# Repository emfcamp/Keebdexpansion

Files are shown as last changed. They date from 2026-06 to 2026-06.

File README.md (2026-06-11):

# KeebDeck Hexpansion

A keyboard hexpansion for the [Tildagon badge](https://tildagon.badge.emfcamp.org/) using the [solder.party KeebDeck Keyboard](https://www.solder.party/docs/keebdeck/keyboard/). Software for the hexpansion is [provided by @sodoku](https://github.com/sodoku/tildagon-keebdeck).

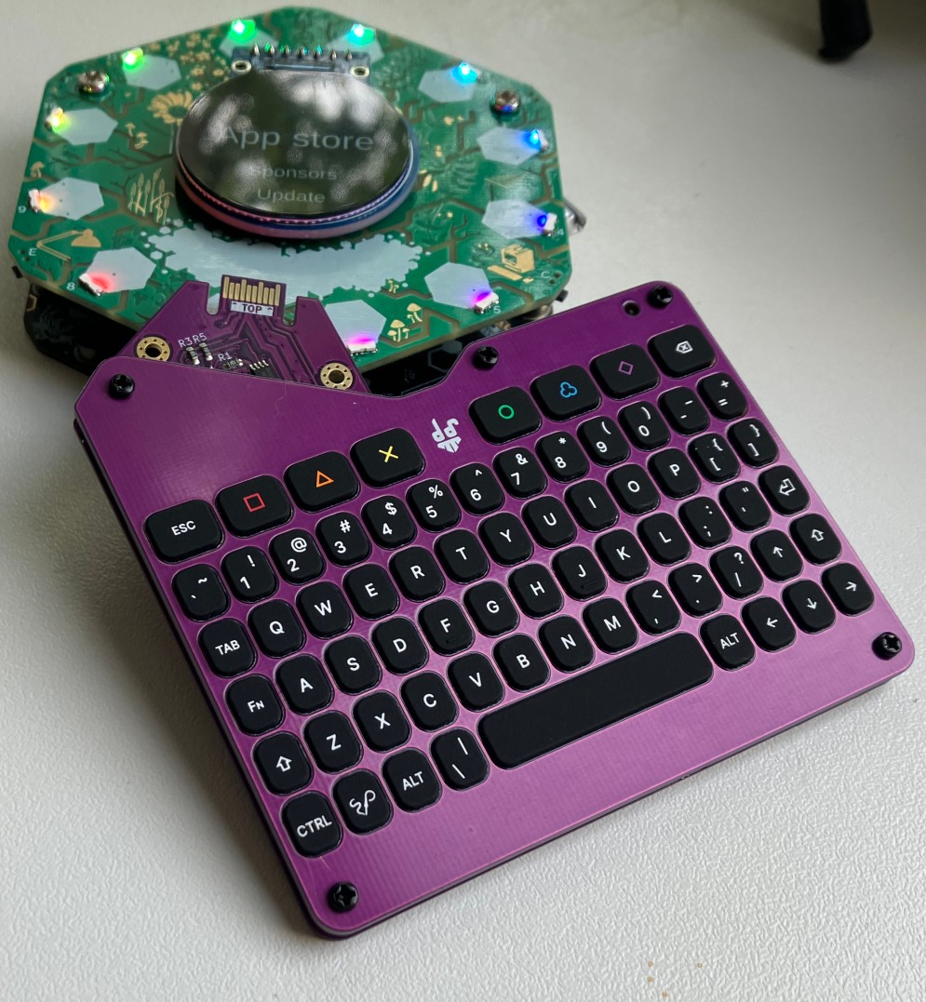
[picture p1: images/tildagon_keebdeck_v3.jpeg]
KeepDeck Hexpansion V3 next to the Tildagon


## Features

- Full layout keyboard
- RGB Backlit keys
- Type in text inputs
- Auto-installs driver when plugged in

Available for EMF 2026 camp ticket holders on the emfcamp website. See [here](https://blog.emfcamp.org/2026/05/28/tildagon-2026-spaceagon/) for more info

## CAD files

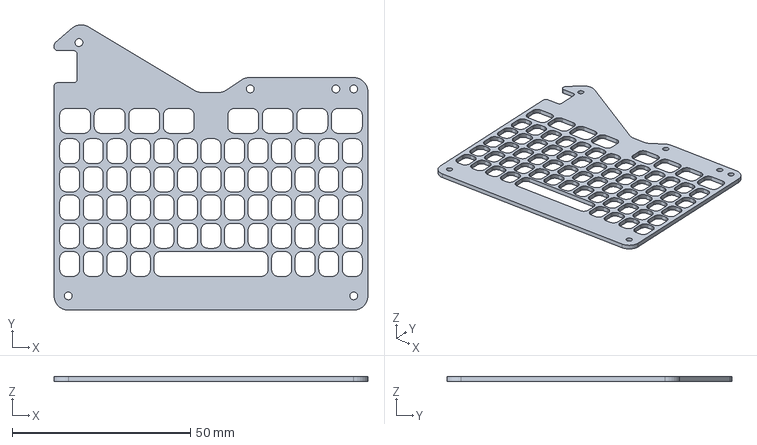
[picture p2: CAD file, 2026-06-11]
KiCad/frontplate/frontplate.step
88.0 x 80.0 x 1.51 mm

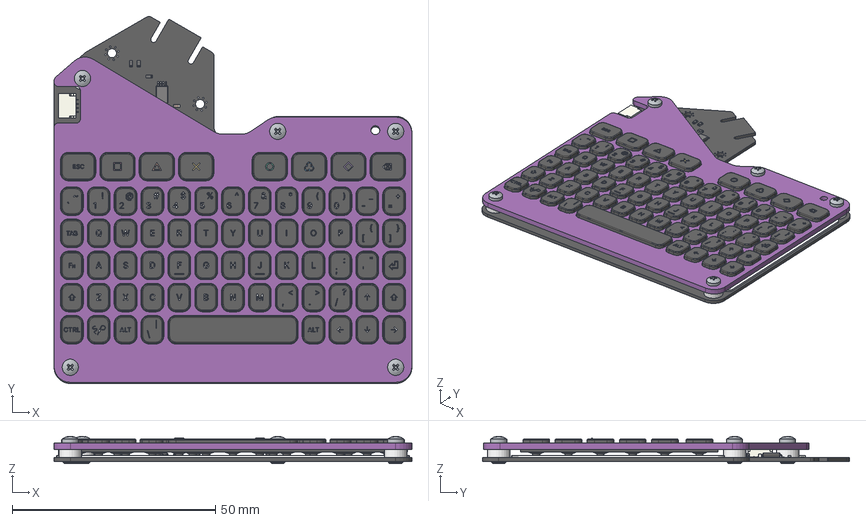
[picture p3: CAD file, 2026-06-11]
KiCad/keebdexpansion.step
88.0 x 90.3 x 6.70 mm
JST_SH_SM04B-SRSS-TB_1x04-1MP_P1.00mm_Horizontal
SMTSO2020CTJ x 5
M2x4 x 5
TSSOP-8_4.4x3mm_P0.65mm
C_0603_1608Metric x 2
C_0402_1005Metric
R_0603_1608Metric x 5
dome_sheet_6x13
keyboard_6x13
frontplate_PCB
TSOT-23-6
main_PCB

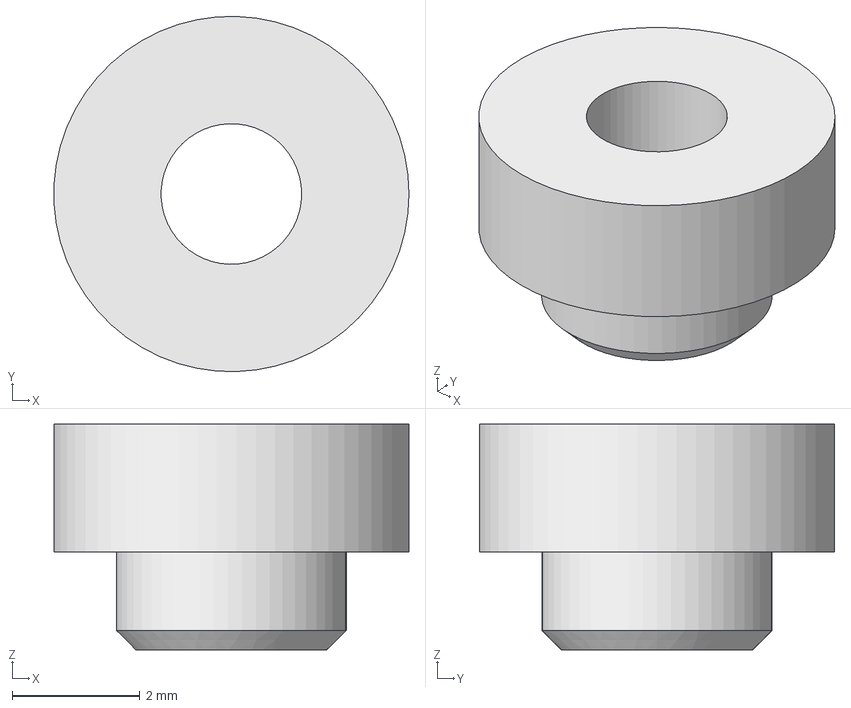
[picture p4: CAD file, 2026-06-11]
KiCad/main/SMTSO2020CTJ.step
5.56 x 5.56 x 3.53 mm

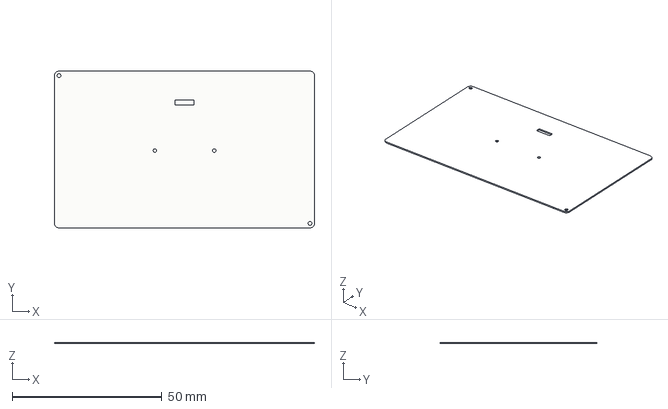
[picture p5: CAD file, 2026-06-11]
KiCad/dome_sheet_6x13.step
86.7 x 52.3 x 0.5 mm

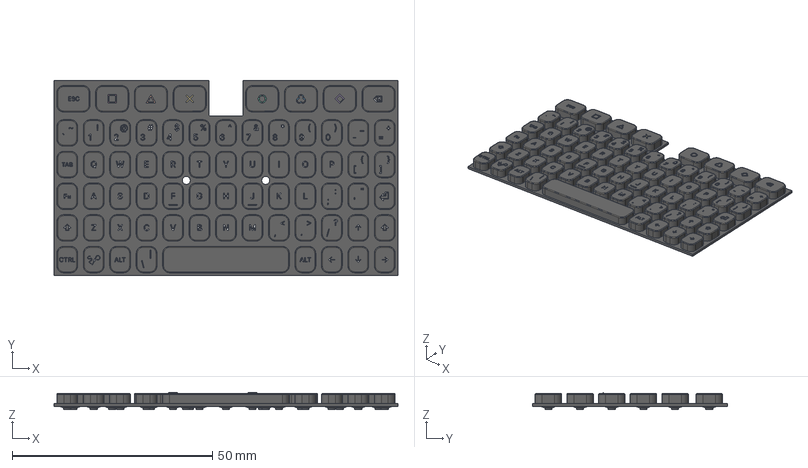
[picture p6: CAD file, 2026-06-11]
KiCad/keyboard_6x13.step
85.8 x 48.6 x 4.25 mm

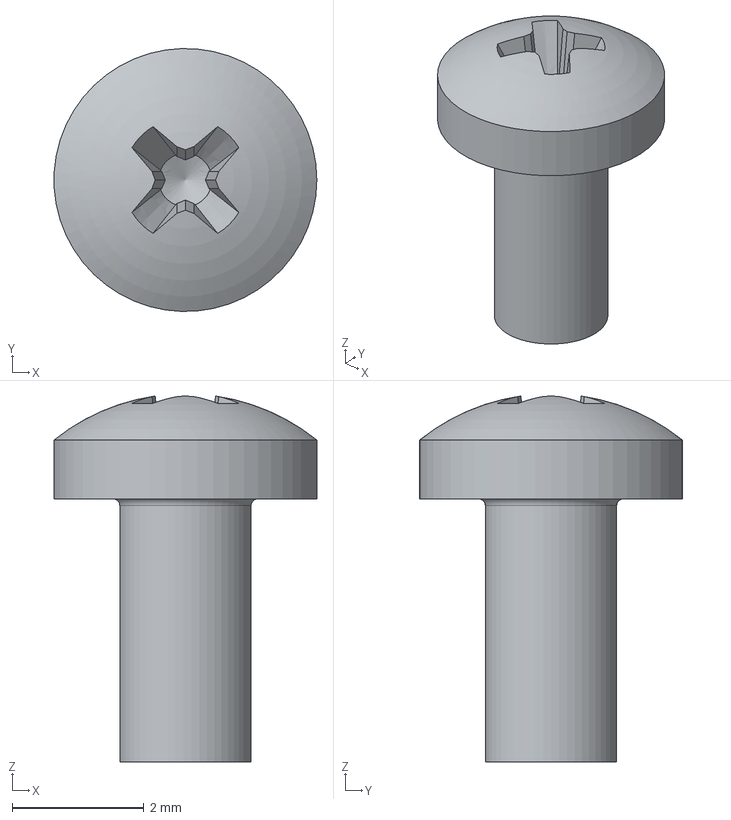
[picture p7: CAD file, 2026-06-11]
KiCad/main/M2x4.step
4.00 x 4.00 x 5.57 mm

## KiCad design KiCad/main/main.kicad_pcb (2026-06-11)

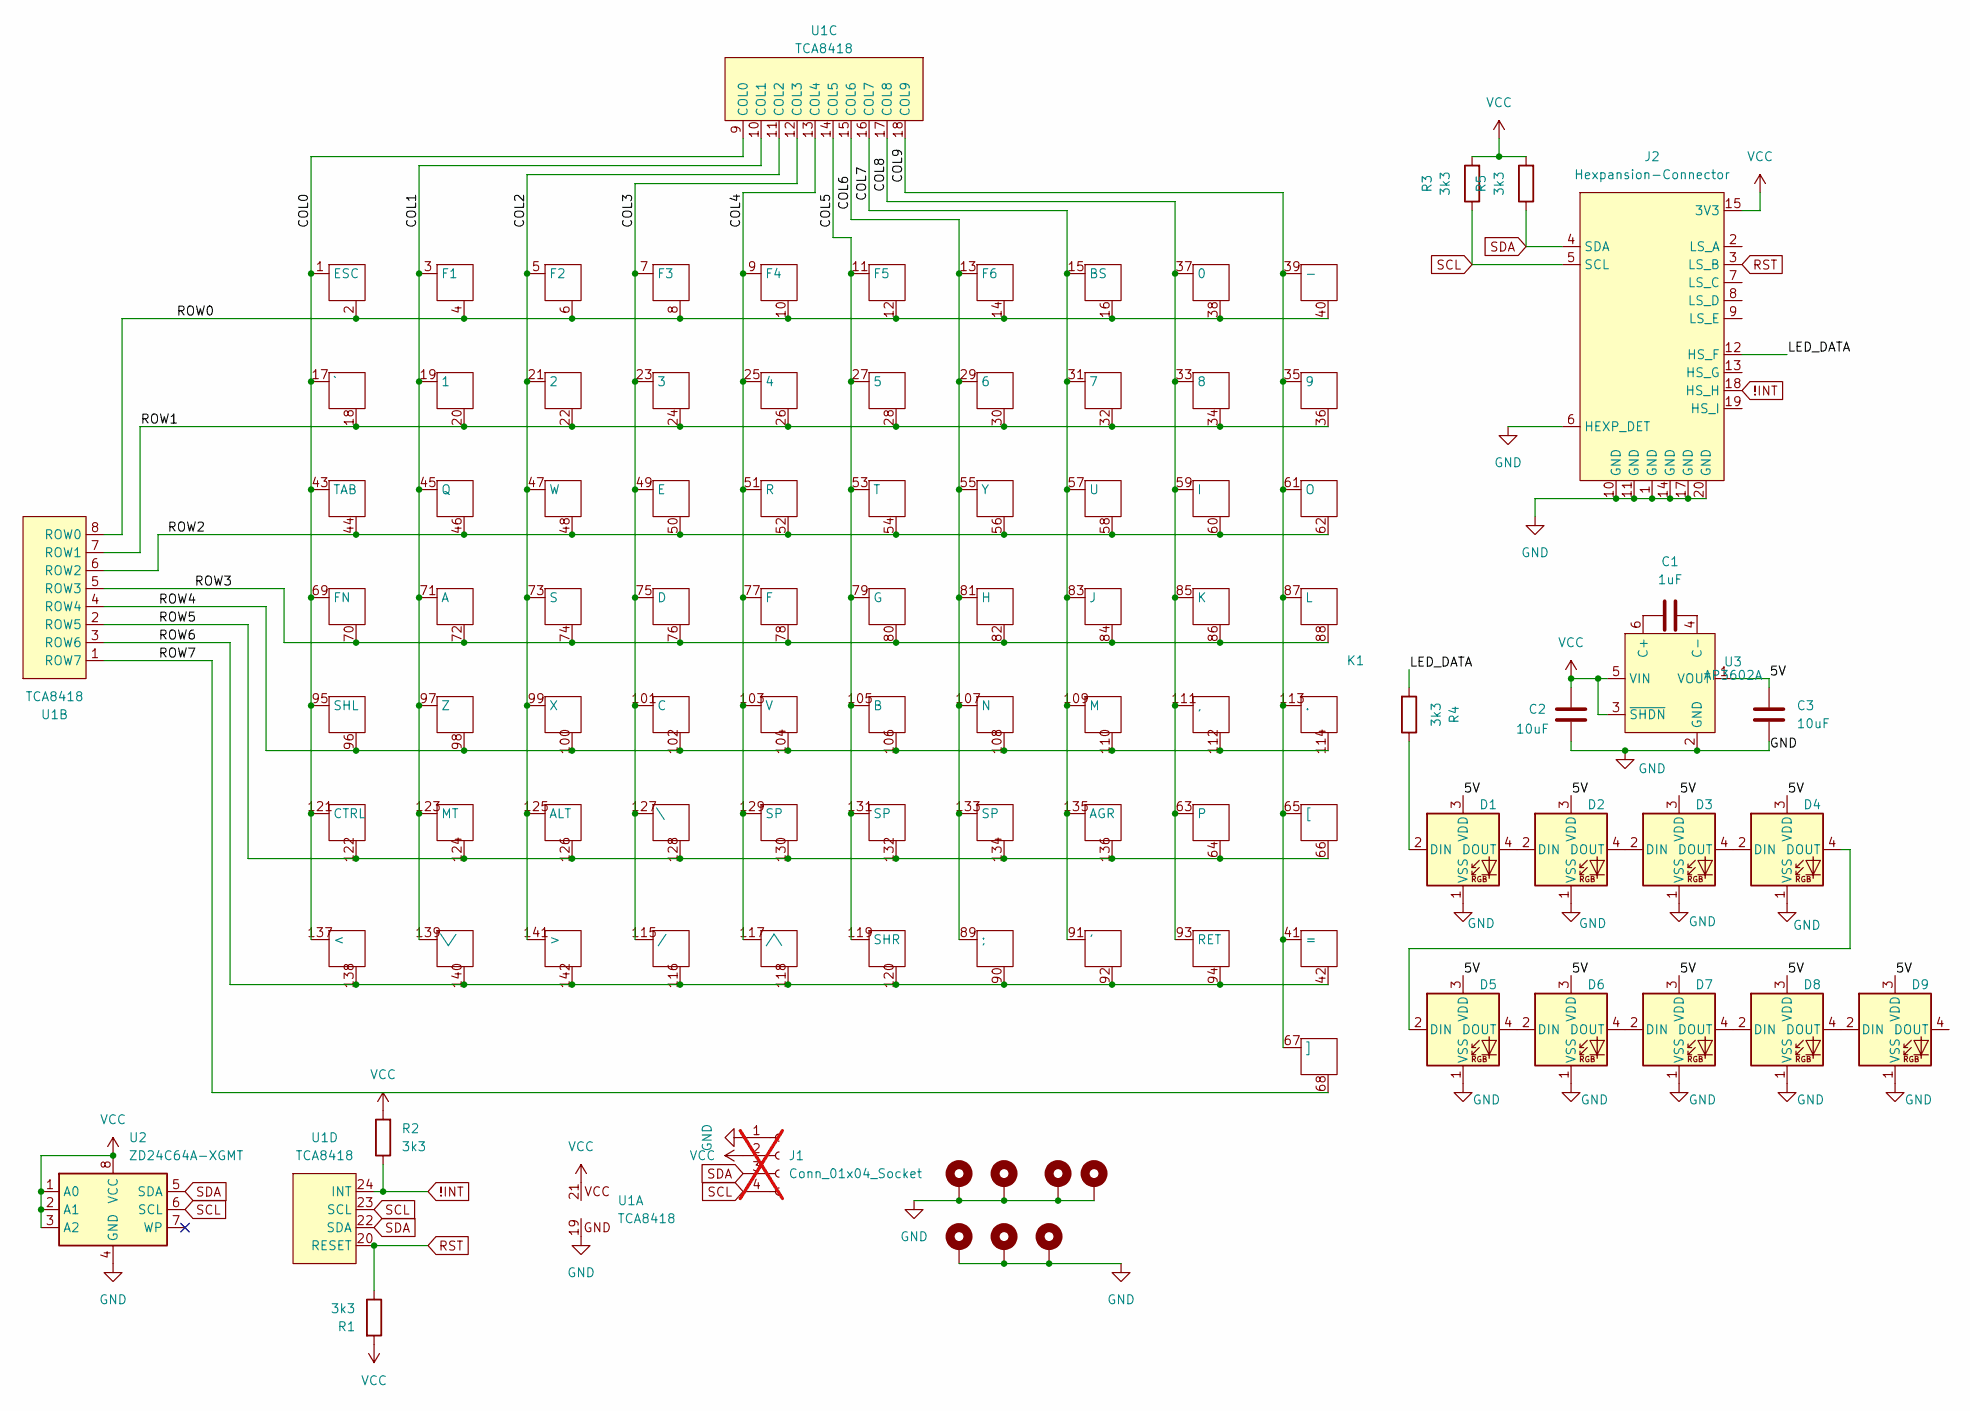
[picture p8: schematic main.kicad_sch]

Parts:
C1: 1uF; C_0402_1005Metric; MPN C2887021
C2, C3: 10uF; C_0603_1608Metric; MPN C3015157
D1, D2, D3, D4, D5, D6, D7, D8, D9: XL-3210RGBC-WS2812B; XL-3210RGBC-2812B; MPN C41413182
H1, H3: MountingHole_Pad; MountingHole_2.2mm_M2_Pad_Via
H2, H4, H5, H6, H7: SMTSO2020CTJ; LCSC C2915626
J1: Conn_01x04_Socket; JST_SH_SM04B-SRSS-TB_1x04-1MP_P1.00mm_Horizontal; not fitted
J2: Hexpansion-Connector; hexpansion-edge-connector
K1: keyboard_arturo182
R1, R2, R3, R4, R5: 3k3; R_0603_1608Metric_Pad0.98x0.95mm_HandSolder
U1: TCA8418; WQFN-24-1EP_4x4mm_P0.5mm_EP2.45x2.45mm
U2: ZD24C64A-XGMT; TSSOP-8_4.4x3mm_P0.65mm; MPN C2875852
U3: AP3602A; TSOT-23-6_HandSoldering; MPN C460358

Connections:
!INT: J2.18 (HS_H), R2.1, U1.24 (INT)
/5V: C3.2, D1.3 (VDD), D2.3 (VDD), D3.3 (VDD), D4.3 (VDD), D5.3 (VDD), D6.3 (VDD), D7.3 (VDD), D8.3 (VDD), D9.3 (VDD), U3.1 (VOUT)
/COL0: K1.1 (ESC), K1.17 (`), K1.43 (TAB), K1.69 (FN), K1.95 (SHL), K1.121 (CTRL), K1.137 (<), U1.9 (COL0)
/COL1: K1.3 (F1), K1.19 (1), K1.45 (Q), K1.71 (A), K1.97 (Z), K1.123 (MT), K1.139 (\/), U1.10 (COL1)
/COL2: K1.5 (F2), K1.21 (2), K1.47 (W), K1.73 (S), K1.99 (X), K1.125 (ALT), K1.141 (>), U1.11 (COL2)
/COL3: K1.7 (F3), K1.23 (3), K1.49 (E), K1.75 (D), K1.101 (C), K1.115 (/), K1.127 (\), U1.12 (COL3)
/COL4: K1.9 (F4), K1.25 (4), K1.51 (R), K1.77 (F), K1.103 (V), K1.117 (/\), K1.129 (SP), U1.13 (COL4)
/COL5: K1.11 (F5), K1.27 (5), K1.53 (T), K1.79 (G), K1.105 (B), K1.119 (SHR), K1.131 (SP), U1.14 (COL5)
/COL6: K1.13 (F6), K1.29 (6), K1.55 (Y), K1.81 (H), K1.89 (;), K1.107 (N), K1.133 (SP), U1.15 (COL6)
/COL7: K1.15 (BS), K1.31 (7), K1.57 (U), K1.83 (J), K1.91 ('), K1.109 (M), K1.135 (AGR), U1.16 (COL7)
/COL8: K1.33 (8), K1.37 (0), K1.59 (I), K1.63, K1.85 (K), K1.93 (RET), K1.111 (,), U1.17 (COL8)
/COL9: K1.35 (9), K1.39 (-), K1.41 (=), K1.61 (O), K1.65 ([), K1.67 (]), K1.87 (L), K1.113 (.), U1.18 (COL9)
/LED_DATA: J2.12 (HS_F), R4.2
/ROW0: K1.2, K1.4, K1.6, K1.8, K1.10, K1.12, K1.14, K1.16, K1.38, K1.40, U1.8 (ROW0)
/ROW1: K1.18, K1.20, K1.22, K1.24, K1.26, K1.28, K1.30, K1.32, K1.34, K1.36, U1.7 (ROW1)
/ROW2: K1.44, K1.46, K1.48, K1.50, K1.52, K1.54, K1.56, K1.58, K1.60, K1.62, U1.6 (ROW2)
/ROW3: K1.70, K1.72, K1.74, K1.76, K1.78, K1.80, K1.82, K1.84, K1.86, K1.88, U1.5 (ROW3)
/ROW4: K1.96, K1.98, K1.100, K1.102, K1.104, K1.106, K1.108, K1.110, K1.112, K1.114, U1.4 (ROW4)
/ROW5: K1.64, K1.66, K1.122, K1.124, K1.126, K1.128, K1.130, K1.132, K1.134, K1.136, U1.2 (ROW5)
/ROW6: K1.42, K1.90, K1.92, K1.94, K1.116, K1.118, K1.120, K1.138, K1.140, K1.142, U1.3 (ROW6)
/ROW7: K1.68, U1.1 (ROW7)
GND: C2.1, C3.1, D1.1 (VSS), D2.1 (VSS), D3.1 (VSS), D4.1 (VSS), D5.1 (VSS), D6.1 (VSS), D7.1 (VSS), D8.1 (VSS), D9.1 (VSS), H1.1, H2.1, H3.1, H4.1, H5.1, H6.1, H7.1, J1.1, J2.1 (GND), J2.6 (HEXP_DET), J2.10 (GND), J2.11 (GND), J2.14 (GND), J2.17 (GND), J2.20 (GND), U1.19, U2.4 (GND), U3.2 (GND)
unnamed: D1.2 (DIN), R4.1
unnamed: D1.4 (DOUT), D2.2 (DIN)
unnamed: D2.4 (DOUT), D3.2 (DIN)
unnamed: D3.4 (DOUT), D4.2 (DIN)
unnamed: D4.4 (DOUT), D5.2 (DIN)
unnamed: D5.4 (DOUT), D6.2 (DIN)
unnamed: D6.4 (DOUT), D7.2 (DIN)
unnamed: D7.4 (DOUT), D8.2 (DIN)
unnamed: D8.4 (DOUT), D9.2 (DIN)
unnamed: C1.1, U3.6 (C+)
unnamed: C1.2, U3.4 (C-)
RST: J2.3 (LS_B), R1.1, U1.20 (RESET)
SCL: J1.4, J2.5 (SCL), R3.1, U1.23 (SCL), U2.6 (SCL)
SDA: J1.3, J2.4 (SDA), R5.1, U1.22 (SDA), U2.5 (SDA)
VCC: C2.2, J1.2, J2.15 (3V3), J2.16 (3V3), R1.2, R2.2, R3.2, R5.2, U1.21, U2.1 (A0), U2.2 (A1), U2.3 (A2), U2.8 (VCC), U3.3 (~SHDN), U3.5 (VIN)

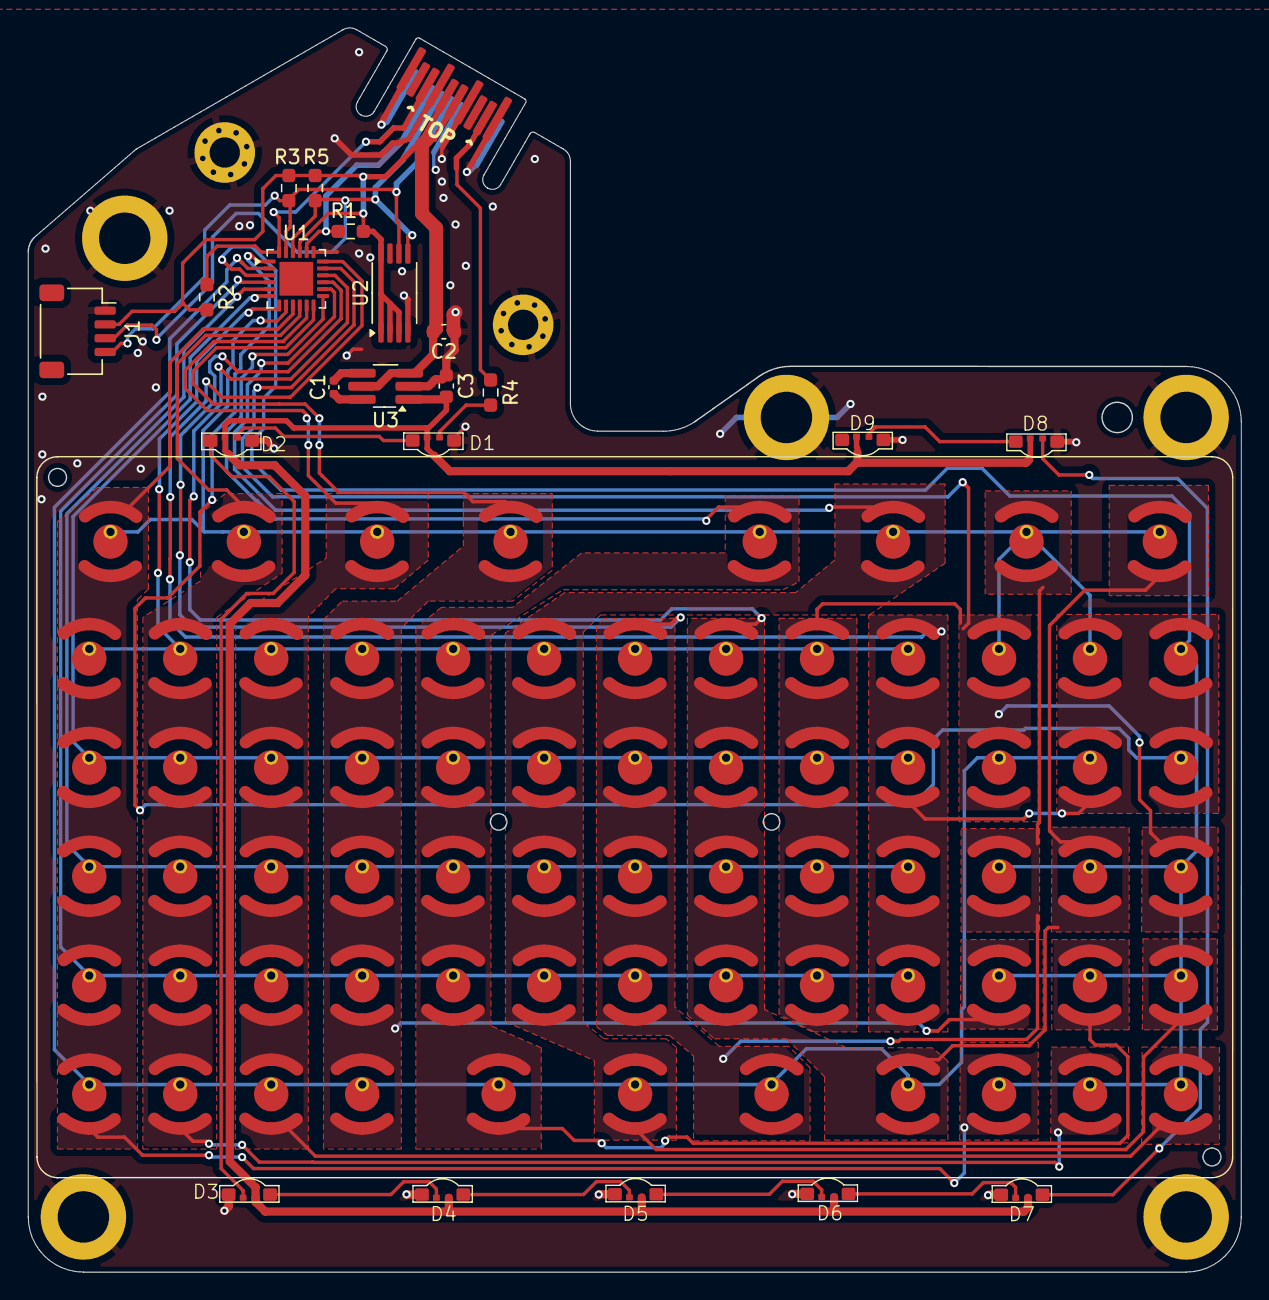
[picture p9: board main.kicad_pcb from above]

Board: 2 copper layers, 88.0 x 90.3 mm, 30 parts (0 on the bottom side), 37 nets.

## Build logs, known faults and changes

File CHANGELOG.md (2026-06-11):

# Changelog

## Revision 3 (as manufactured for EMF Camp)

- switch back to high speed pins
- Change shape
- Move standoffs to bottom PCB
- Add RGB LEDs and power conversion for them
- Add art
- Generate and add 3D models

## Revision 2

- switch to low speed pins
- keyboard works only with polling
- leds working (no dimming)
- new working eeprom

## Revision 1

- keyboard fully functional using interupt
- eeprom unsupported
- leds pin connection missing
- reset pin connection missing

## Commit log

2026-06-11 Modify for EMF camp - Change shape - Move standoffs to bottom PCB - Add RGB LEDs and power conversion for them - Add art - Generate and add 3D models
    [M2x4.step, SMTSO2020CTJ.step, dome_sheet_6x13.step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]
2026-06-11 Convert board cutouts to polygons to work around a STEP export bug
    [frontplate.kicad_pcb]
